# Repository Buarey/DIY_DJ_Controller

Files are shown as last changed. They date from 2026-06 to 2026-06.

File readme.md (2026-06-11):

# DIY DJ Controller



Homemade CDJ-style DJ controller with a 3D-printed enclosure, hand-built electronics, and custom firmware.

This repository documents:
- the current stable Mixxx prototype
- the firmware and Mixxx mapping that make it work
- the next hardware direction for a cleaner v2 build
- open-source hardware, firmware, and documentation for builders who want to contribute

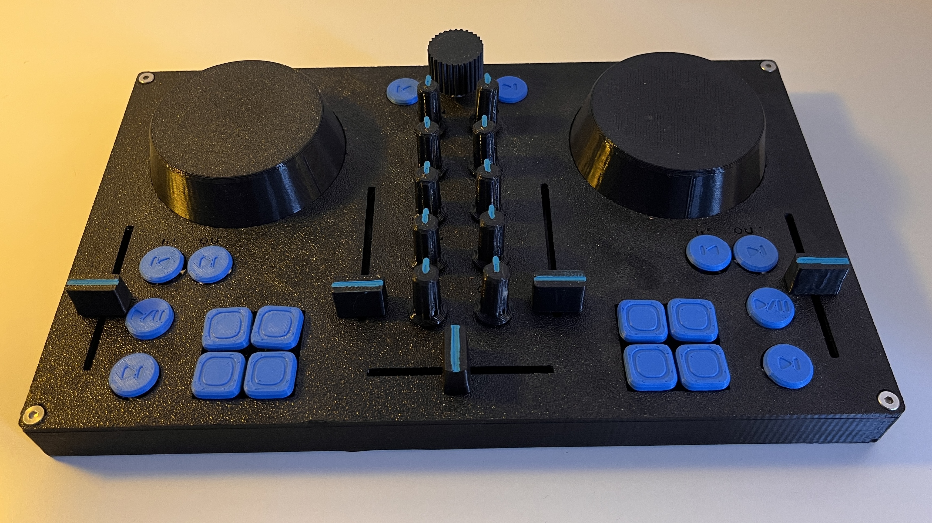
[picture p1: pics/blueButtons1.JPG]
DIY DJ controller with blue buttons


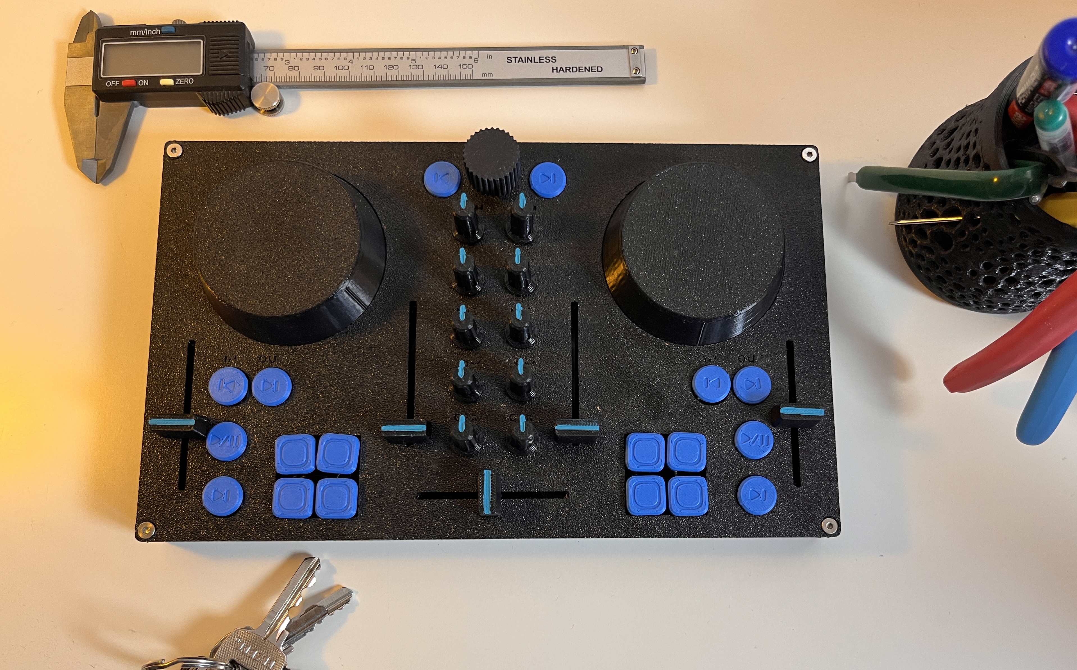
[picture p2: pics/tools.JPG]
DIY DJ controller with tools


<table>
  <tr>
    <td>Prototype top view before final buttons</td>
    <td>Hand-wired controller electronics</td>
  </tr>
  <tr>
    <td>Fusion 360 top assembly render</td>
    <td>Fusion 360 internal assembly render</td>
  </tr>
</table>

## Status

- `v1` is the stable Mixxx-focused version
- the controller has been built, flashed, and used successfully as a working prototype
- Rekordbox was tested, but the jog wheels never became usable enough for a real workflow
- because of that, Rekordbox is not a supported target for this hardware revision

## Current Version

- `MCU`: SparkFun Pro Micro / ATmega32U4
- `Firmware`: PlatformIO + Arduino + `MIDIUSB`
- `Inputs`: `PCF8575` for buttons, `74HC4067` for analog controls, 3 rotary encoders
- `Mechanical`: custom 3D-printed enclosure designed in Fusion 360
- `Software target`: Mixxx

The current prototype includes:
- two-deck transport and loop control
- EQ, filter, gain, volume, tempo, and crossfader control
- jog wheels
- music browsing and load controls

## V1 Hardware Summary

- `MCU`: SparkFun Pro Micro / ATmega32U4
- `Button expander`: `PCF8575` for 16 buttons
- `Analog mux`: `74HC4067` for 15 potentiometers
- `Encoders`: 3 total
  - 1 browse encoder
  - 2 jog wheel encoders
- `Encoder model`: Alps `EC11E` vertical rotary encoder, `H20mm`
- `Button model`: Omron `B3F-40xx`, 12x12 mm THT tactile switch
- `Direct buttons on MCU`: `A1`, `A2`, `A3`
- `Potentiometers`: 15 total
  - `Linear model`: `B103` 75 mm linear slide potentiometer, 10 kOhm
  - `Rotary model`: TT Electronics `P0915N` vertical rotary potentiometer

## V1 Materials List

This is the practical parts list for rebuilding the current working v1 prototype.

| Qty | Material | Notes |
| --- | --- | --- |
| 1 | SparkFun Pro Micro / ATmega32U4 board | The KiCad v1 schematic uses a USB-C Pro Micro clone footprint. Use the matching USB cable for the board you build with. |
| 1 | `PCF8575` / HW-331 16-bit I2C IO expander module | Handles the 16 deck buttons. |
| 1 | `CD74HC4067` / `74HC4067` 16-channel analog multiplexer module | Handles the 15 analog controls. |
| 18 | Omron `B3F-40xx` 12x12 mm THT tactile switches | 16 deck buttons plus 2 direct music-selection buttons. |
| 3 | Alps `EC11E` vertical rotary encoders, `H20mm` | 1 browse encoder plus 2 jog wheel encoders. |
| 10 | TT Electronics `P0915N` vertical rotary potentiometers | Gain, EQ, filter, and other rotary controls. |
| 5 | `B103` 75 mm linear slide potentiometers, 10 kOhm | Deck volume, tempo, and crossfader controls. |
| 1 | 3D-printed enclosure body | `3D models/DIY_CDJ_body.stl`. |
| 1 | 3D-printed enclosure lid | `3D models/DIY_CDJ_lid.stl`. |
| 1 each | 3D-printed caps and control parts | `crossfader.stl`, `cue.stl`, `encoder.stl`, `joggingWheel.stl`, `knob.stl`, `performance-pad.stl`, and `play-pause.stl`. |
| As needed | Hookup wire, solder, and 2.54 mm headers | The stable v1 prototype is hand-wired, not PCB-based. |

The firmware currently defines 3 direct music-selection inputs on `A1`, `A2`, and `A3`, but the KiCad v1 schematic places 18 tactile switches total. Add one extra switch if you wire all 3 direct inputs. The schematic also contains 16 resistor placeholders with no values or footprints assigned yet, so treat those as schematic TODOs rather than an order-ready BOM line.

## V1 Wiring Summary

These are the important firmware-defined connections for the current working Mixxx version.

### Wiring Diagrams

<p>
  Arduino wiring
  VCC wiring
  GND wiring
  Pull-up wiring
  Sensor signal wiring
</p>

### I2C / Button Expander

- `SDA` -> pin `2`
- `SCL` -> pin `3`
- `PCF8575` address is auto-detected on boot in the `0x20` to `0x27` range

### 74HC4067 Multiplexer

- `MUX signal` -> `A0`
- `S0` -> pin `15`
- `S1` -> pin `14`
- `S2` -> pin `16`
- `S3` -> pin `10`

### Rotary Encoders

- `Browse encoder` -> pins `4` and `5`
- `Jog wheel 1` -> pins `8` and `9`
- `Jog wheel 2` -> pins `6` and `7`

### Direct Buttons

- `A3` -> note `76`
- `A2` -> note `77`
- `A1` -> note `78`

## V1 Current Input Map

### PCF8575 Buttons

- `Button 0` -> Deck 1 Loop Out
- `Button 1` -> Deck 1 Loop In
- `Button 2` -> Deck 1 Hotcue 3
- `Button 3` -> Deck 1 Hotcue 4
- `Button 4` -> Deck 1 Hotcue 1
- `Button 5` -> Deck 1 Hotcue 2
- `Button 6` -> Deck 1 Cue
- `Button 7` -> Deck 1 Play/Pause
- `Button 8` -> Deck 2 Hotcue 4
- `Button 9` -> Deck 2 Hotcue 3
- `Button 10` -> Deck 2 Hotcue 1
- `Button 11` -> Deck 2 Hotcue 2
- `Button 12` -> Deck 2 Cue
- `Button 13` -> Deck 2 Play/Pause
- `Button 14` -> Deck 2 Loop In
- `Button 15` -> Deck 2 Loop Out

### Potentiometers

- `Pot 0 / CC 10` -> Deck 1 Gain
- `Pot 1 / CC 11` -> Deck 2 Gain
- `Pot 2 / CC 12` -> Deck 1 High EQ
- `Pot 3 / CC 13` -> Deck 2 High EQ
- `Pot 4 / CC 14` -> Deck 1 Mid EQ
- `Pot 5 / CC 15` -> Deck 2 Mid EQ
- `Pot 6 / CC 16` -> Deck 1 Low EQ
- `Pot 7 / CC 17` -> Deck 2 Low EQ
- `Pot 8 / CC 18` -> Deck 1 Filter
- `Pot 9 / CC 19` -> Deck 2 Filter
- `Pot 10 / CC 20` -> Deck 2 Volume
- `Pot 11 / CC 21` -> Deck 2 Tempo
- `Pot 12 / CC 22` -> Deck 1 Volume
- `Pot 13 / CC 23` -> Crossfader
- `Pot 14 / CC 24` -> Deck 1 Tempo

### Browser And Jog Controls

- `Browse encoder / CC 25` -> library scroll
- `A1 / note 78` -> Load selected track to Deck 1
- `A2 / note 77` -> Load selected track to Deck 2
- `A3 / note 76` -> Enter or expand selected folder
- `Jog wheel on pins 8/9 / CC 26` -> currently mapped to Deck 2
- `Jog wheel on pins 6/7 / CC 27` -> currently mapped to Deck 1

## V1 Firmware

The current firmware lives in `CDJ_firmware/src/main.cpp`.

### Current Behavior

- auto-detects the `PCF8575` on boot
- configures the expander pins as input pull-high
- reads 16 buttons through the `PCF8575`
- reads 15 analog controls through the `74HC4067`
- reads 3 rotary encoders
- reads direct top buttons on `A1`, `A2`, and `A3`
- sends MIDI note and CC messages through `MIDIUSB`
- uses an additional filter on the browse encoder to reduce event spam in Mixxx

### Build Target

`CDJ_firmware/platformio.ini` currently targets:

```ini
[env:sparkfun_promicro16]
platform = atmelavr
board = sparkfun_promicro16
framework = arduino
lib_deps =
  arduino-libraries/MIDIUSB @ ^1.0.5
```

## Repo Layout

- `CDJ_firmware/` - firmware source and PlatformIO config
- `controllers/mixx_Mapping/` - Mixxx XML and JS mapping
- `controllers/rekordbox/` - Rekordbox mapping reference and notes
- `pics/` - renders and prototype photos
- `reference circuits/` - circuit reference images
- `PCB/` - KiCad schematic, PCB, and custom symbols/footprints
- `3D models/` - printable parts and Fusion 360 source archive
- `CONTRIBUTING.md` - contribution guide
- `.github/` - issue templates, pull request template, and CI workflow

## Source Of Truth

- `Firmware`: `CDJ_firmware/src/main.cpp`
- `Mixxx XML mapping`: `controllers/mixx_Mapping/DJC-DIY.midi.xml`
- `Mixxx JS mapping`: `controllers/mixx_Mapping/DJC-DIY-scripts.js`

For exact control behavior, use those files instead of this README.

## Contributing

Contributions are welcome. The most useful contributions right now are practical build reports, Mixxx mapping fixes, firmware cleanup, PCB review, parts substitutions, enclosure fit notes, and documentation improvements.

Before starting a large hardware or firmware change, open an issue so the direction can be discussed. Small documentation fixes can go straight to a pull request.

Useful starter work:

- test the current Mixxx mapping on another OS or Mixxx version
- document compatible Pro Micro clones, encoders, buttons, and potentiometers
- improve wiring photos or assembly notes
- review the KiCad v1 schematic and PCB TODOs
- add real build notes for 3D-print settings and fit adjustments

See `CONTRIBUTING.md` for the full workflow and pull request checklist.

## Getting Started

### Firmware

1. Install [PlatformIO](https://platformio.org/) in VS Code.
2. Open `CDJ_firmware/`.
3. Connect the SparkFun Pro Micro by USB.
4. Build or upload:

```bash
pio run
pio run --target upload
```

### Mixxx

Copy these files into your Mixxx controller mapping folder:

- `controllers/mixx_Mapping/DJC-DIY.midi.xml`
- `controllers/mixx_Mapping/DJC-DIY-scripts.js`

Then enable the mapping in Mixxx.

## Important Notes

- The stable path for this project is Mixxx, not Rekordbox.
- The prototype is still hand-wired and not PCB-based yet.
- The current jog wheel assignment is swapped between physical control and deck mapping.
- Rekordbox support should be treated as future hardware research, not a feature of this version.

## V2 Plan

V2 is a hardware redesign focused on one goal: keep a single `USB-C` cable to the computer and add a built-in `3.5 mm` headphone cue output.

- `Master` stays on the computer side
- the controller provides only `Headphones / Cue`
- the project stays Mixxx-first

### Electronics Plan

- `Prototype MCU`: `SparkFun Thing Plus ESP32-S3`
- `Custom PCB MCU`: `ESP32-S3-WROOM-1`
- `Headphone audio`: `Adafruit TLV320DAC3100` or equivalent small I2S headphone DAC/codec
- `External ports`: one `USB-C`, one `3.5 mm TRS` headphone jack
- `Existing controls to keep initially`: `PCF8575`, `74HC4067`, jog encoders, browse encoder, buttons, and potentiometers

### Core Connections

- `USB-C` -> `ESP32-S3`
- `ESP32-S3 I2S` -> `TLV320DAC3100` audio data
- `ESP32-S3 I2C` -> `TLV320DAC3100` configuration
- `TLV320DAC3100` -> `3.5 mm TRS` headphone jack
- `ESP32-S3` -> existing control hardware

### Firmware Work

- port the controller logic from `ATmega32U4` to `ESP32-S3`
- expose one composite USB device with `MIDI + audio`
- keep the current control behavior as close to `v1` as possible
- send Mixxx cue audio to the headphone DAC

### Rekordbox Note

`ESP32-S3` is a much better platform for future USB experiments, but it does not guarantee Rekordbox compatibility or working jog wheels. V2 should still be treated as a Mixxx-first design.

## License

This project uses separate licenses by file type:

| Files | License |
| --- | --- |
| Firmware and controller mappings | GNU General Public License v3.0 only (`GPL-3.0-only`) |
| PCB, wiring, CAD, and 3D hardware design files | CERN Open Hardware Licence Version 2 - Strongly Reciprocal (`CERN-OHL-S-2.0`) |
| Documentation, photos, videos, and other media | Creative Commons Attribution 4.0 International (`CC-BY-4.0`) |

See `LICENSE.md`, `LICENSE-SOFTWARE.txt`, `LICENSE-HARDWARE.txt`, and `LICENSE-DOCS.txt` for details.

This project was inspired by my friend [@mandiclab](https://github.com/mandiclab) and the [djc-diy](https://github.com/mandiclab/djc-diy) project.

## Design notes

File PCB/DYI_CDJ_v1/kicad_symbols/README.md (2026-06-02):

# CDJ v1 KiCad Module Library

This project-local library contains schematic symbols and through-hole module footprints for the breakout boards shown in the project notes:

- `PCF8575_Module_HW331`
- `CD74HC4067_Module_Generic`
- `Arduino_Pro_Micro_USB_C`

KiCad should load them through the project-local `sym-lib-table` and `fp-lib-table` files.

The Arduino Pro Micro USB-C library was imported from:

https://github.com/jueta/Arduino_Pro_Micro_USB_C-Kicad-Library

The two module footprints were rebuilt from the linked product photos and corroborating supplier dimensions. They are drawn as component-side views: when the module is face-up, the silkscreen labels match the real board labels. Before ordering a PCB, print the footprints at 1:1 scale and place the physical boards over them.

Measurement references:

- Linked PCF8575 product photos and `21 mm x 32 mm` dimension image: https://www.aliexpress.com/item/1005009340294771.html
- Equivalent Open-Smart PCF8575 module listed as `33 mm x 21 mm`: https://www.tinytronics.nl/en/communication-and-signals/io-converters/open-smart-pcf8575-io-expander-module-16-extra-io-pins
- Linked HW-178 CD74HC4067 product photos: https://www.aliexpress.com/item/1005006309366590.html
- HW-178 supplier dimensions listed as `17 mm x 40 mm`: https://besomi.com/jo_en/hw-178-cd74hc4067-besomi-mux-module.html
- Equivalent standard 74HC4067 module dimensions listed as `40 mm x 18 mm`: https://protosupplies.com/product/16-ch-analog-digital-mux-module/

- Header pitch is 2.54 mm.
- PCF8575 board outline is nominally `21 mm x 32 mm`.
- PCF8575 left row, top to bottom: `P10`, `P11`, `P12`, `P13`, `P14`, `P15`, `P16`, `P17`, `VDD`, `GND`.
- PCF8575 right row, top to bottom: `P07`, `P06`, `P05`, `P04`, `P03`, `P02`, `P01`, `P00`, `VDD`, `GND`.
- PCF8575 bottom row, left to right: `GND`, `VCC`, `SDA`, `SCL`, `INT`.
- CD74HC4067 HW-178 board outline is nominally `40 mm x 18 mm`. Some suppliers report the width as `17 mm`; the header geometry is the same.
- CD74HC4067 left row, top to bottom: `C15` through `C0`.
- CD74HC4067 right row, top to bottom: `SIG`, `S3`, `S2`, `S1`, `S0`, `EN`, `VCC`, `GND`.
- Arduino Pro Micro USB-C board body is assumed to be `36.80 mm x 17.70 mm`.
- Arduino Pro Micro USB-C top row, USB-C on the left, left to right: `RAW`, `GND`, `RST`, `VCC`, `A3`, `A2`, `A1`, `A0`, `15`, `14`, `16`, `10`.
- Arduino Pro Micro USB-C bottom row, USB-C on the left, left to right: `TX0`, `RX1`, `GND`, `GND`, `2`, `3`, `4`, `5`, `6`, `7`, `8`, `9`.
- Board outlines match your exact modules. Daughterboard mounting holes are shown on `F.Fab` as reference marks only; they are intentionally not drilled into the carrier PCB.

The symbols use named pad numbers such as `SDA`, `P00`, and `C15`, so symbol pins and footprint pads map by signal name instead of fragile numeric pin order.

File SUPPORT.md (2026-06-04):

# Support

For build help, open an issue and include:

- Your operating system.
- Mixxx or Rekordbox version.
- Board model and USB connector type.
- Photos of the wiring or PCB area involved.
- The exact firmware commit or release you used.
- What you expected, what happened, and what you already tried.

For quick reports, use the issue templates. For larger design ideas, open a feature request before starting a big pull request.

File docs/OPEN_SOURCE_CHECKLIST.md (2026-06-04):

# Open Source Publishing Checklist

Use this checklist before making the GitHub repository public or announcing it.

## Repository

- Add the license files and `LICENSE.md` overview.
- Keep generated files out of commits: KiCad backups, `fp-info-cache`, `.kicad_prl`, PlatformIO build output, and `.DS_Store`.
- Confirm no personal files, credentials, private notes, or unfinished exports are tracked.
- Push the open-source preparation commit.

## GitHub Settings

- Set the repository visibility to public when ready.
- Enable Issues.
- Enable Discussions if you want build-help conversations separate from bug reports.
- Add topics: `diy-electronics`, `dj-controller`, `midi-controller`, `mixxx`, `platformio`, `arduino`, `kicad`, `open-hardware`, `3d-printing`.
- Add labels: `firmware`, `hardware`, `pcb`, `3d-models`, `mapping`, `docs`, `bug`, `enhancement`, `good first issue`, `help wanted`, `safety`.

## First Release

- Tag the current working Mixxx prototype as `v1.0.0`.
- Attach or link the firmware source, Mixxx mapping files, STL files, wiring images, and build notes.
- State that Rekordbox is experimental/unsupported for the current hardware revision.
- Mention known issues, especially swapped jog assignment and prototype hand-wiring.

## Community

- Create 3-5 starter issues that are genuinely approachable.
- Add one pinned issue for build reports.
- Ask contributors to include photos and version details when reporting hardware problems.

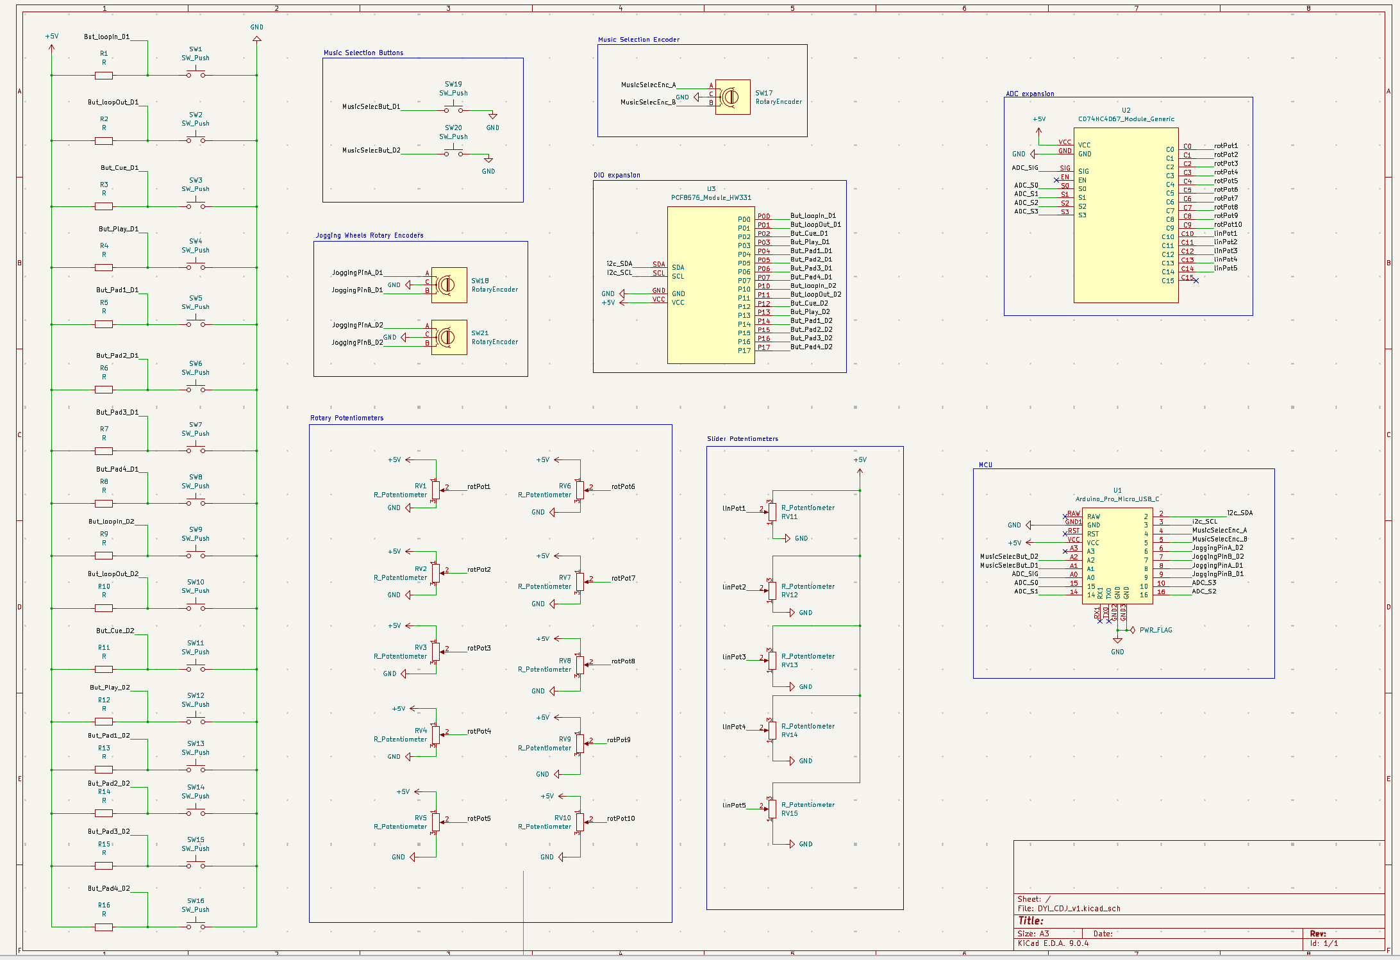
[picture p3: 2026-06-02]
pics/schematics_v1.png

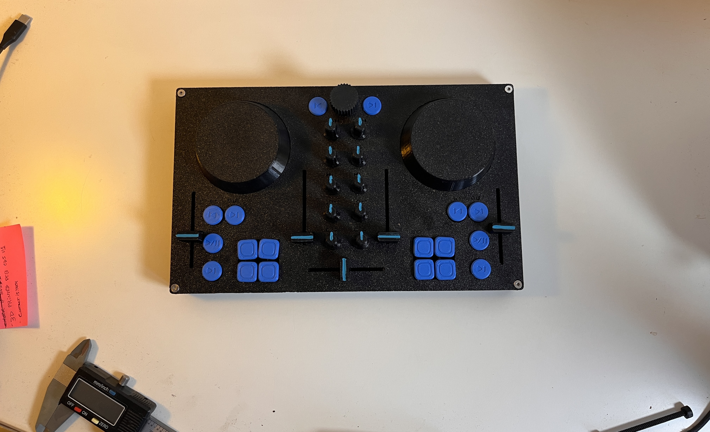
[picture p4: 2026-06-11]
pics/blueButtons3.JPG

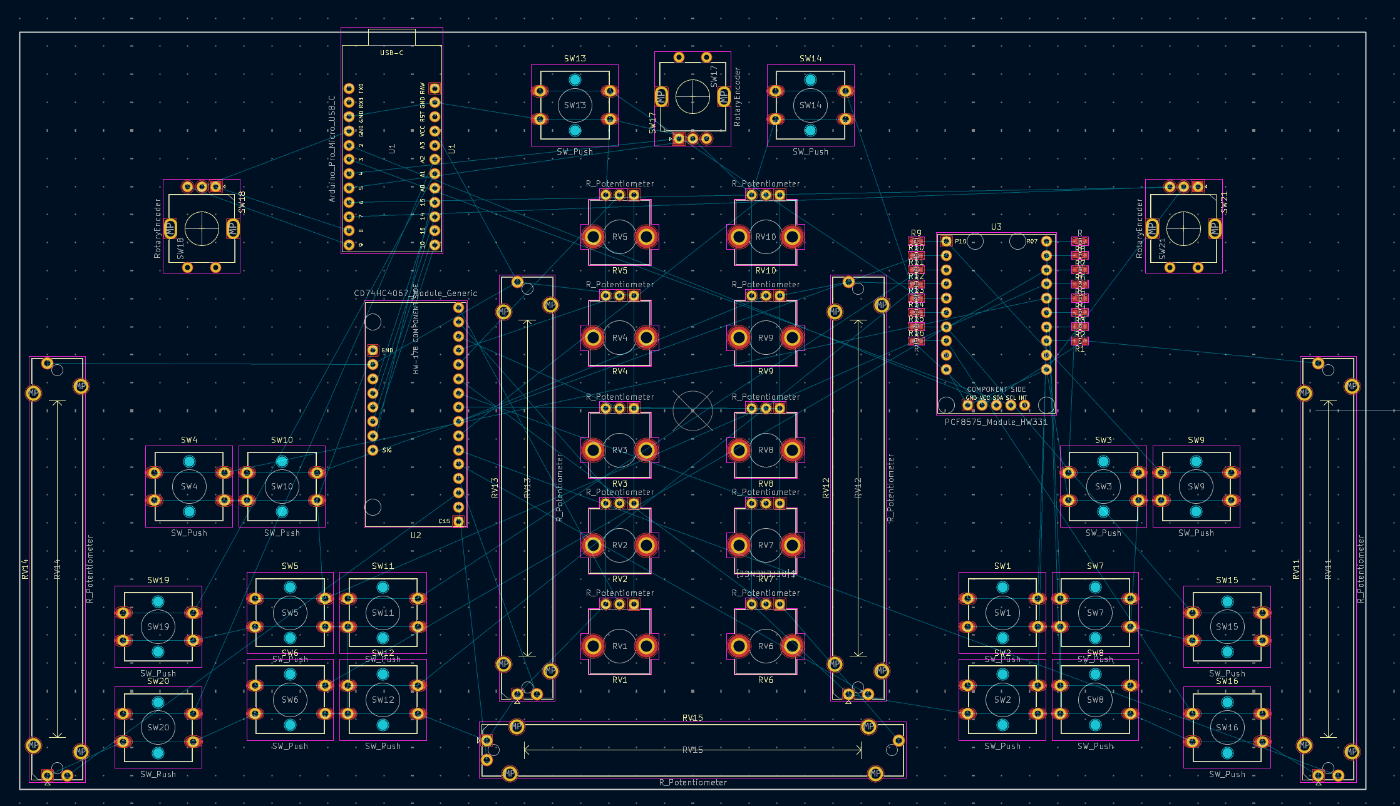
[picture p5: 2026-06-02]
pics/PCB_development_v1.png

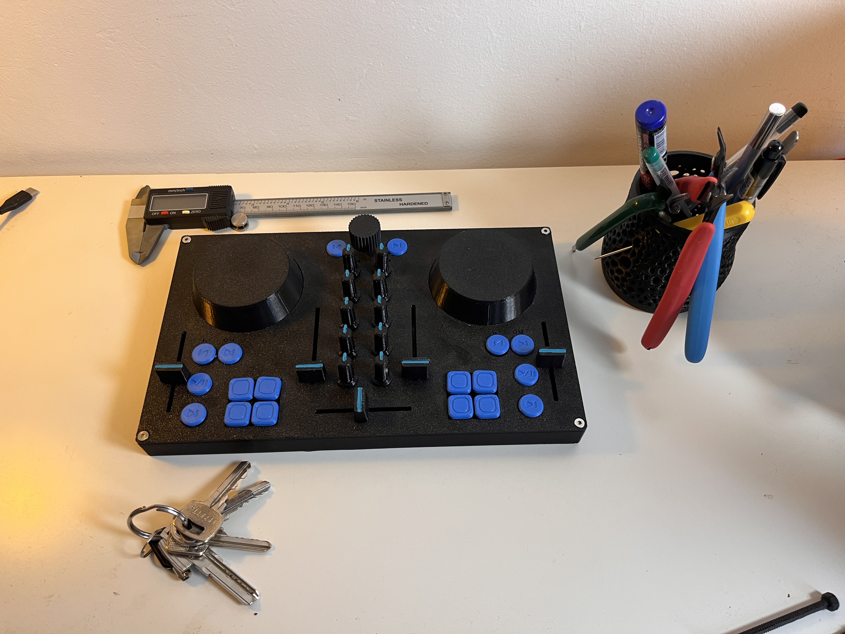
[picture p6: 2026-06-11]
pics/tools2.JPG

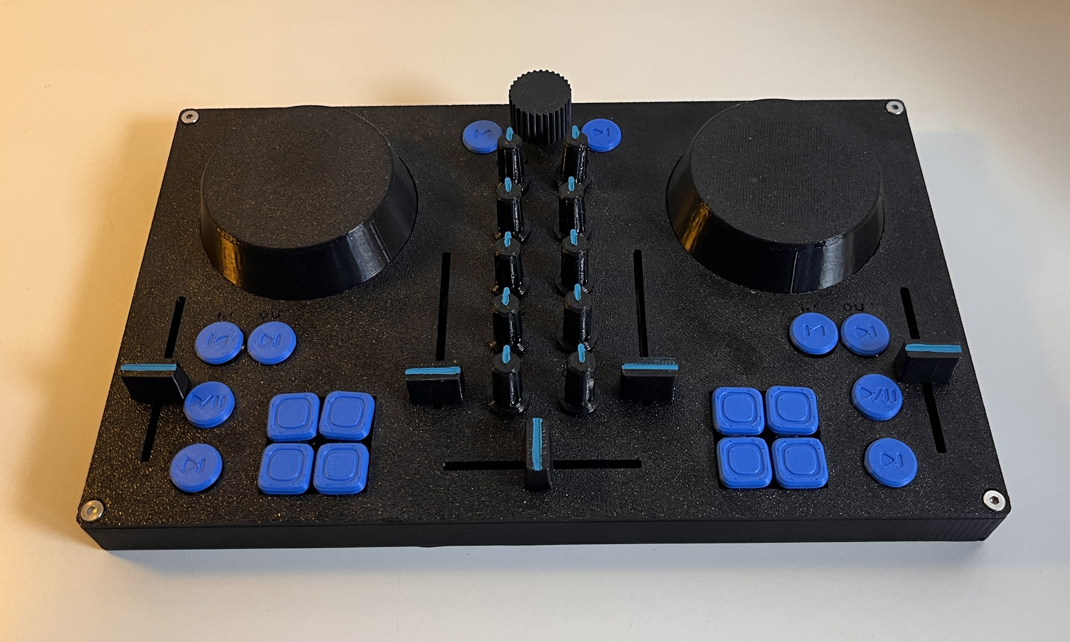
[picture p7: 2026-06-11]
pics/blueButtons4.JPG

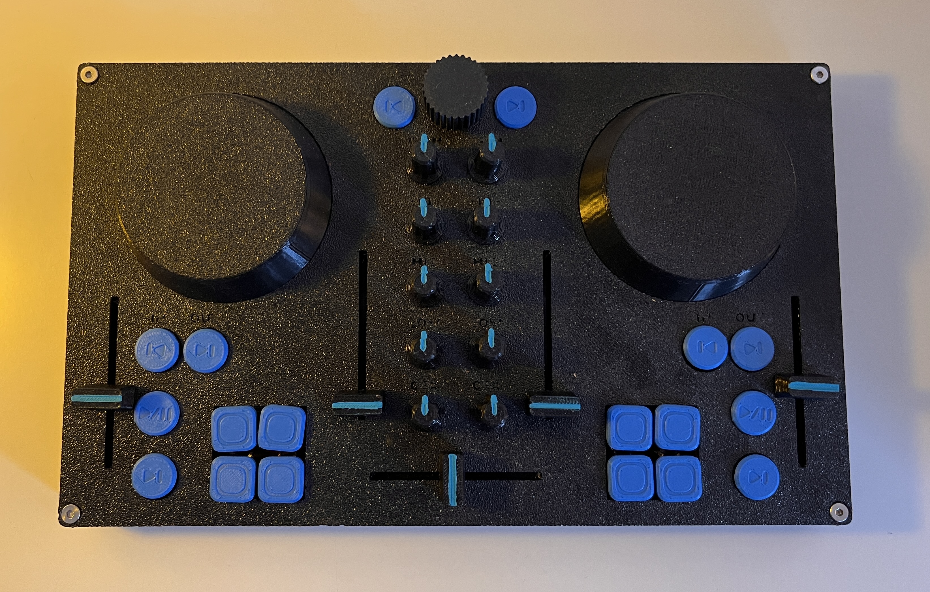
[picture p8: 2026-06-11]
pics/blueButtons2.JPG

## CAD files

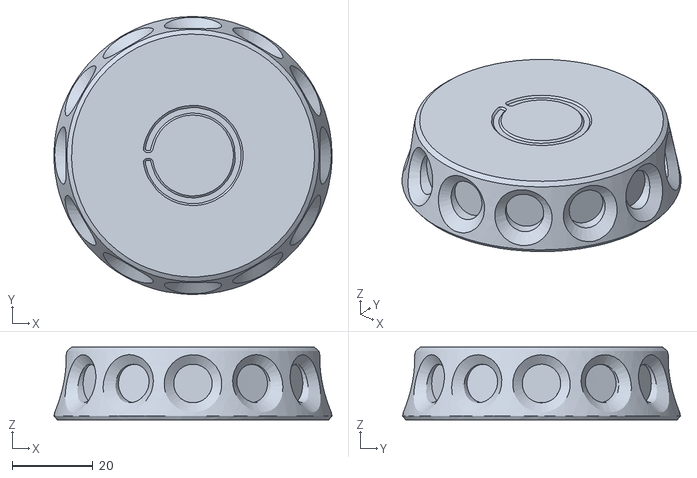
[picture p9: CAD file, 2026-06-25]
3D models/manda_jogwheel_big.stl
69.0 x 69.0 x 18.0

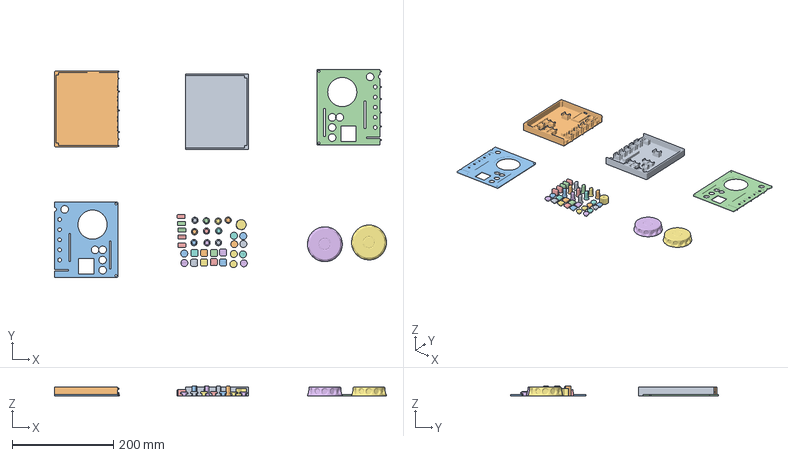
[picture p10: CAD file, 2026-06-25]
3D models/Orca_Slicer_Files/DIY_CDJ.3mf
656.0 x 411.9 x 20.0 mm
DIY_CDJ_body.stl x 2
DIY_CDJ_lid.stl_A
DIY_CDJ_lid.stl_B
crossfader.stl x 5
cue.stl x 2
encoder.stl
knob.stl x 10
performance-pad.stl x 8
play-pause.stl x 2
button_load_track.stl
button_round_clean.stl x 4
manda_jogwheel_big.stl x 2

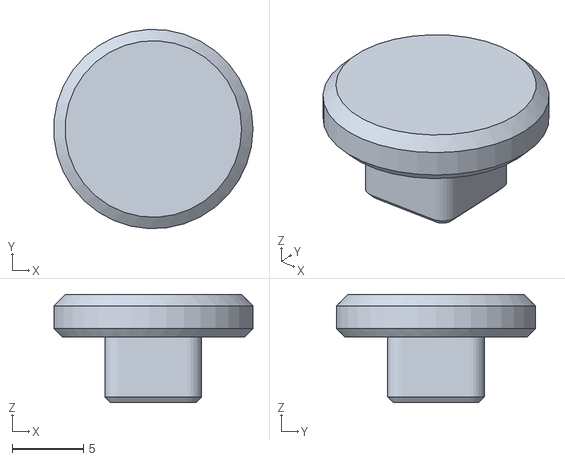
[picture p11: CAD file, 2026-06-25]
3D models/button_round_clean.stl
14.0 x 14.0 x 7.60

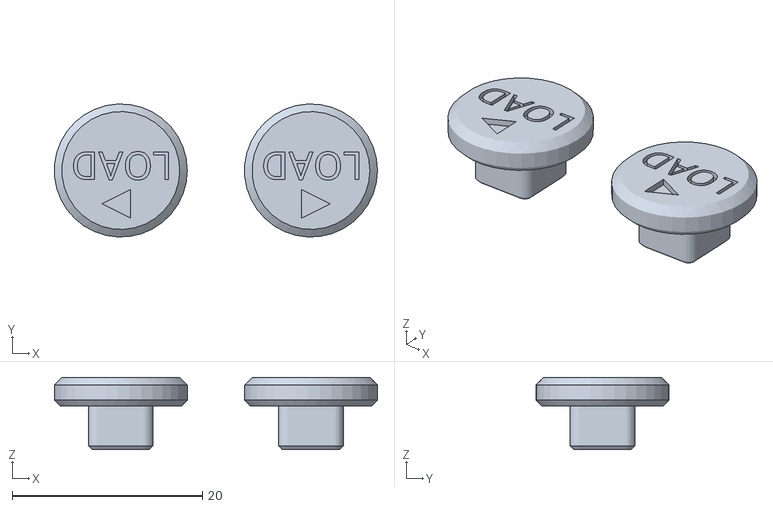
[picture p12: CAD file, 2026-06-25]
3D models/button_load_track.stl
34.0 x 14.0 x 7.60

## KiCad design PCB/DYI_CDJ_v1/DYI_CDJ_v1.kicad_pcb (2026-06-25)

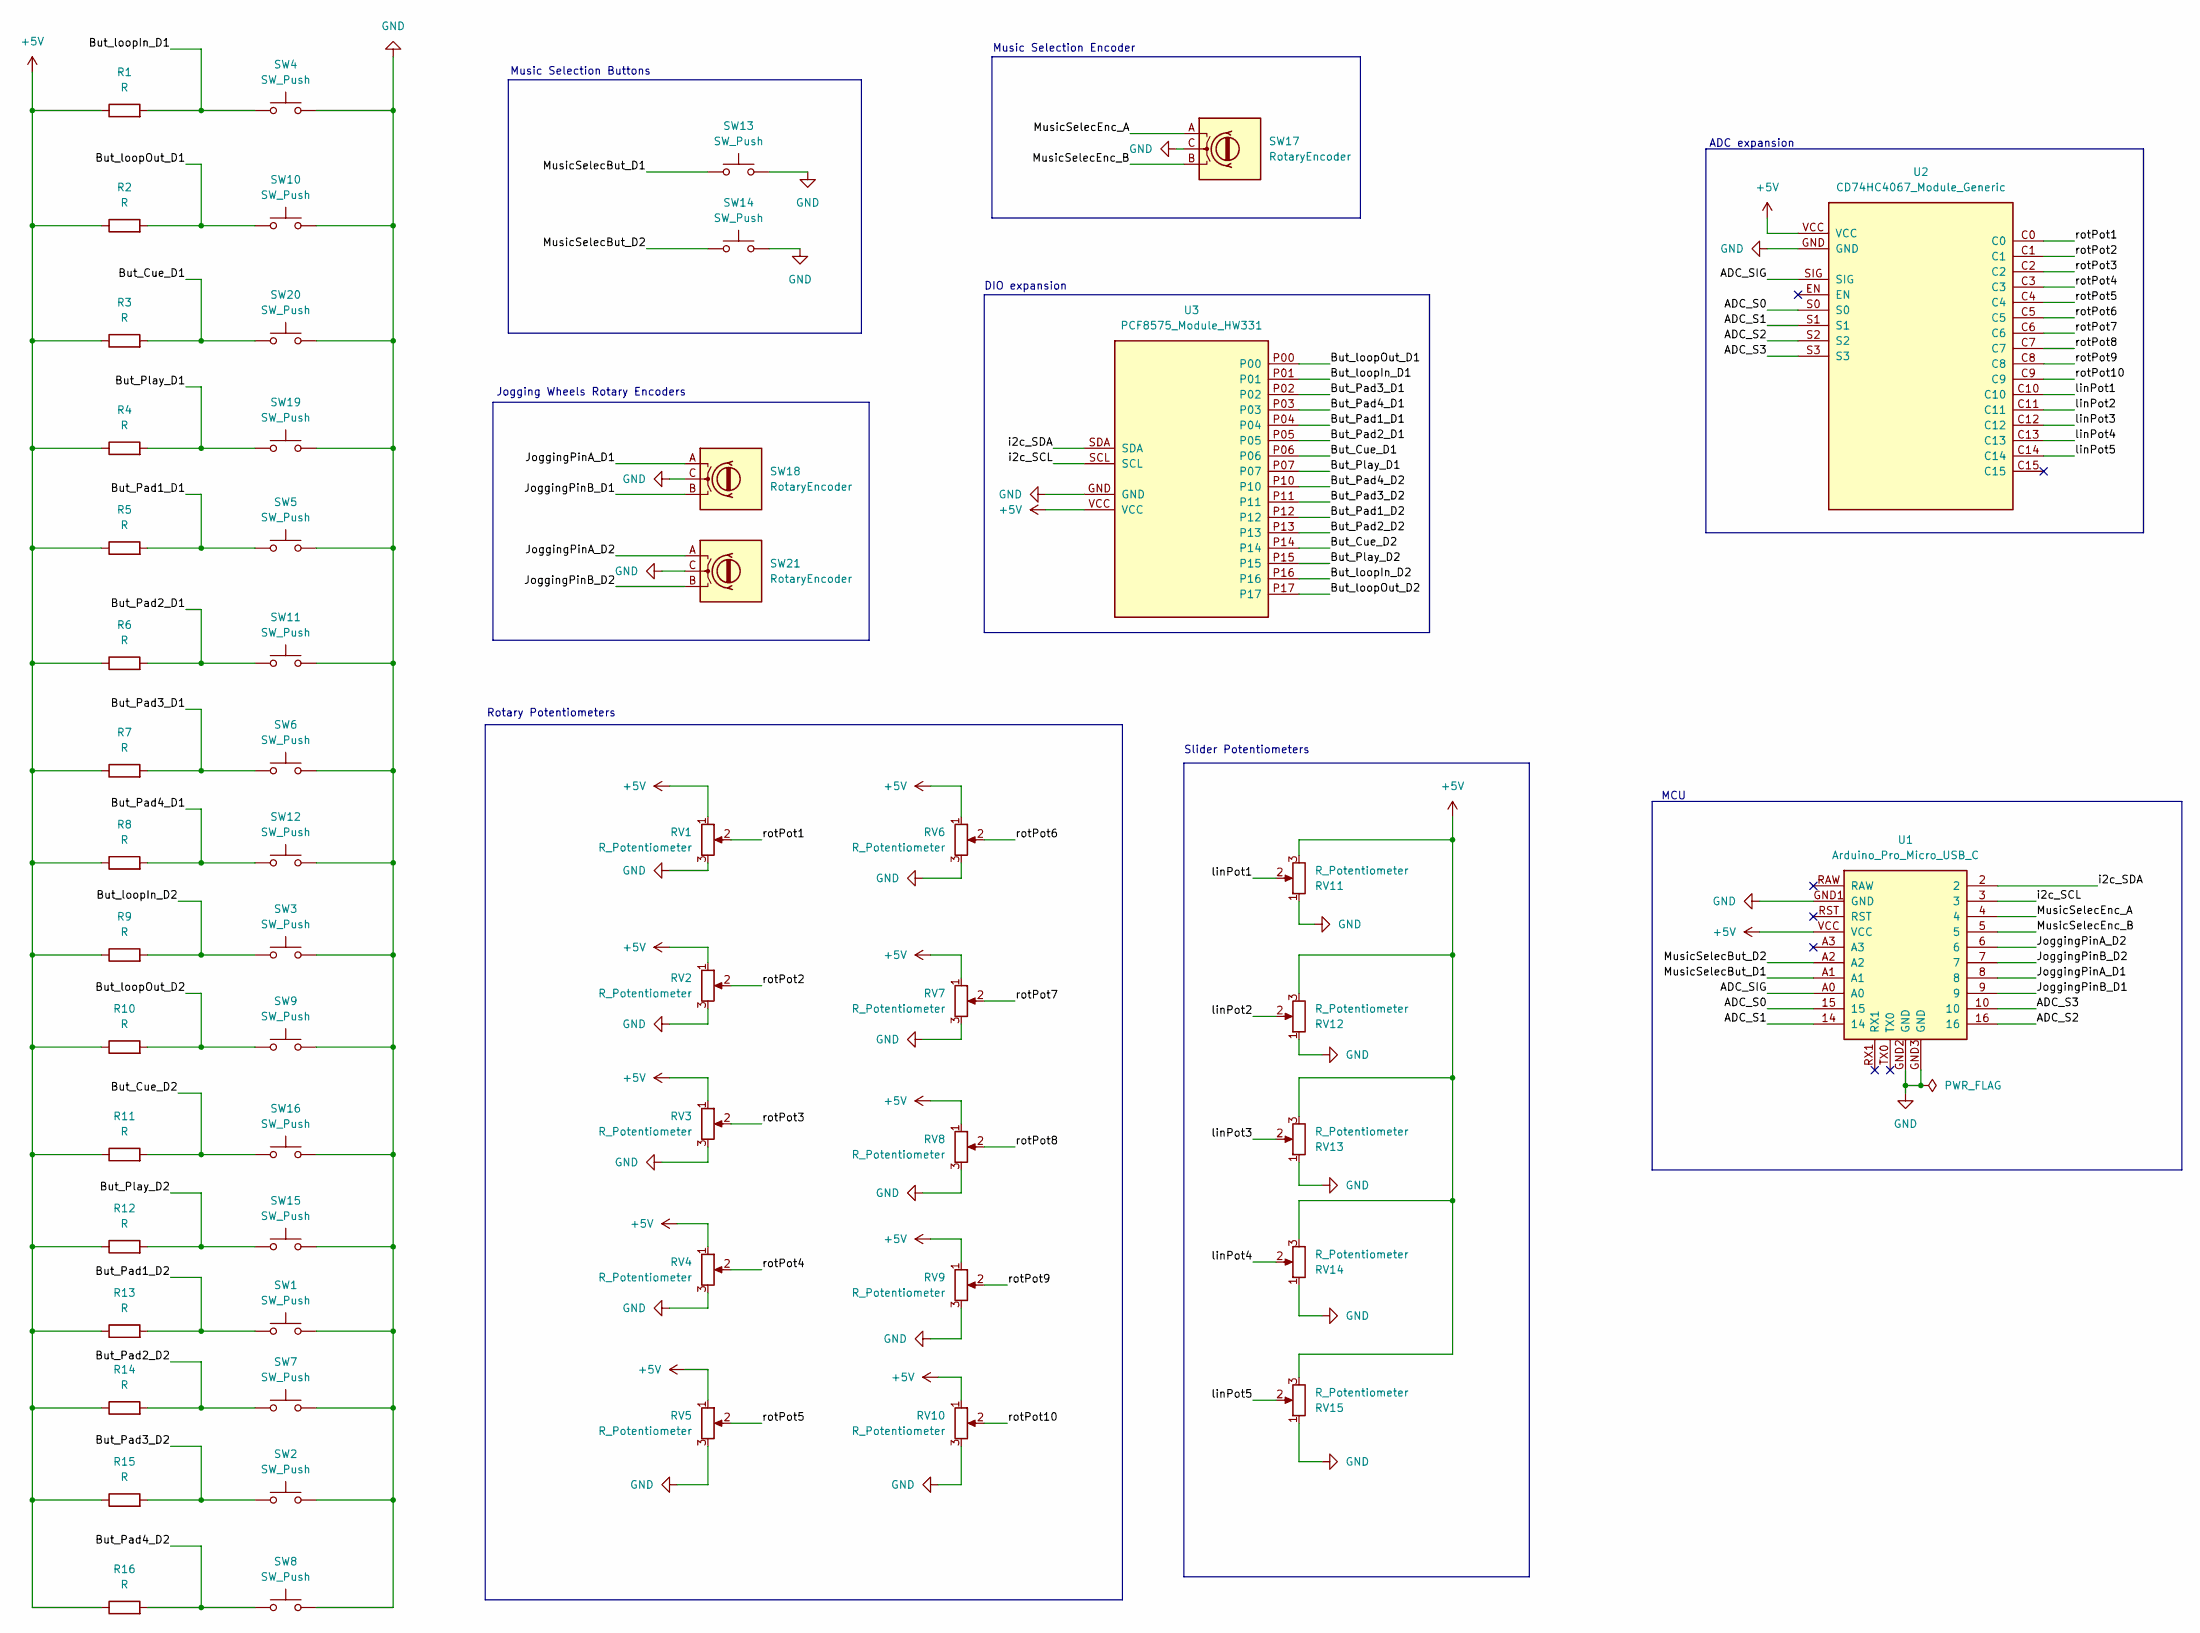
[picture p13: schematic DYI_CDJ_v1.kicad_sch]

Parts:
R1, R2, R3, R4, R5, R6, R7, R8, R9, R10, R11, R12, R13, R14, R15, R16: R; R_Axial_DIN0207_L6.3mm_D2.5mm_P10.16mm_Horizontal
RV1, RV2, RV3, RV4, RV5, RV6, RV7, RV8, RV9, RV10: R_Potentiometer; Potentiometer_TT_P0915N
RV11, RV12, RV13, RV14, RV15: R_Potentiometer; Potentiometer_Bourns_PTA6043_Single_Slide
SW1, SW2, SW3, SW4, SW5, SW6, SW7, SW8, SW9, SW10, SW11, SW12, SW13, SW14, SW15, SW16, SW19, SW20: SW_Push; SW_SPST_Omron_B3F-40xx
SW17, SW18, SW21: RotaryEncoder; RotaryEncoder_Alps_EC11E_Vertical_H20mm
U1: Arduino_Pro_Micro_USB_C; Arduino_Pro_Micro_USB_C_36.8x17.7mm
U2: CD74HC4067_Module_Generic
U3: PCF8575_Module_HW331

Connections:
+5V: R1.1, R2.1, R3.1, R4.1, R5.1, R6.1, R7.1, R8.1, R9.1, R10.1, R11.1, R12.1, R13.1, R14.1, R15.1, R16.1, RV1.1, RV2.1, RV3.1, RV4.1, RV5.1, RV6.1, RV7.1, RV8.1, RV9.1, RV10.1, RV11.3, RV12.3, RV13.3, RV14.3, RV15.3, U1.VCC, U2.VCC, U3.VCC
/ADC_S0: U1.15, U2.S0
/ADC_S1: U1.14, U2.S1
/ADC_S2: U1.16, U2.S2
/ADC_S3: U1.10, U2.S3
/ADC_SIG: U1.A0, U2.SIG
/But_Cue_D1: R3.2, SW20.1, U3.P06
/But_Cue_D2: R11.2, SW16.1, U3.P14
/But_Pad1_D1: R5.2, SW5.1, U3.P04
/But_Pad1_D2: R13.2, SW1.1, U3.P12
/But_Pad2_D1: R6.2, SW11.1, U3.P05
/But_Pad2_D2: R14.2, SW7.1, U3.P13
/But_Pad3_D1: R7.2, SW6.1, U3.P02
/But_Pad3_D2: R15.2, SW2.1, U3.P11
/But_Pad4_D1: R8.2, SW12.1, U3.P03
/But_Pad4_D2: R16.2, SW8.1, U3.P10
/But_Play_D1: R4.2, SW19.1, U3.P07
/But_Play_D2: R12.2, SW15.1, U3.P15
/But_loopIn_D1: R1.2, SW4.1, U3.P01
/But_loopIn_D2: R9.2, SW3.1, U3.P16
/But_loopOut_D1: R2.2, SW10.1, U3.P00
/But_loopOut_D2: R10.2, SW9.1, U3.P17
/JoggingPinA_D1: SW18.A, U1.8
/JoggingPinA_D2: SW21.A, U1.6
/JoggingPinB_D1: SW18.B, U1.9
/JoggingPinB_D2: SW21.B, U1.7
/MusicSelecBut_D1: SW13.1, U1.A1
/MusicSelecBut_D2: SW14.1, U1.A2
/MusicSelecEnc_A: SW17.A, U1.4
/MusicSelecEnc_B: SW17.B, U1.5
/i2c_SCL: U1.3, U3.SCL
/i2c_SDA: U1.2, U3.SDA
/linPot1: RV11.2, U2.C10
/linPot2: RV12.2, U2.C11
/linPot3: RV13.2, U2.C12
/linPot4: RV14.2, U2.C13
/linPot5: RV15.2, U2.C14
/rotPot1: RV1.2, U2.C0
/rotPot2: RV2.2, U2.C1
/rotPot3: RV3.2, U2.C2
/rotPot4: RV4.2, U2.C3
/rotPot5: RV5.2, U2.C4
/rotPot6: RV6.2, U2.C5
/rotPot7: RV7.2, U2.C6
/rotPot8: RV8.2, U2.C7
/rotPot9: RV9.2, U2.C8
/rotPot10: RV10.2, U2.C9
GND: RV1.3, RV2.3, RV3.3, RV4.3, RV5.3, RV6.3, RV7.3, RV8.3, RV9.3, RV10.3, RV11.1, RV12.1, RV13.1, RV14.1, RV15.1, SW1.2, SW2.2, SW3.2, SW4.2, SW5.2, SW6.2, SW7.2, SW8.2, SW9.2, SW10.2, SW11.2, SW12.2, SW13.2, SW14.2, SW15.2, SW16.2, SW17.C, SW18.C, SW19.2, SW20.2, SW21.C, U1.GND1 (GND), U1.GND2 (GND), U1.GND3 (GND), U2.GND, U3.GND

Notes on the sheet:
Music Selection Buttons
Music Selection Encoder
DIO expansion
Jogging Wheels Rotary Encoders
Slider Potentiometers
ADC expansion
Rotary Potentiometers
MCU

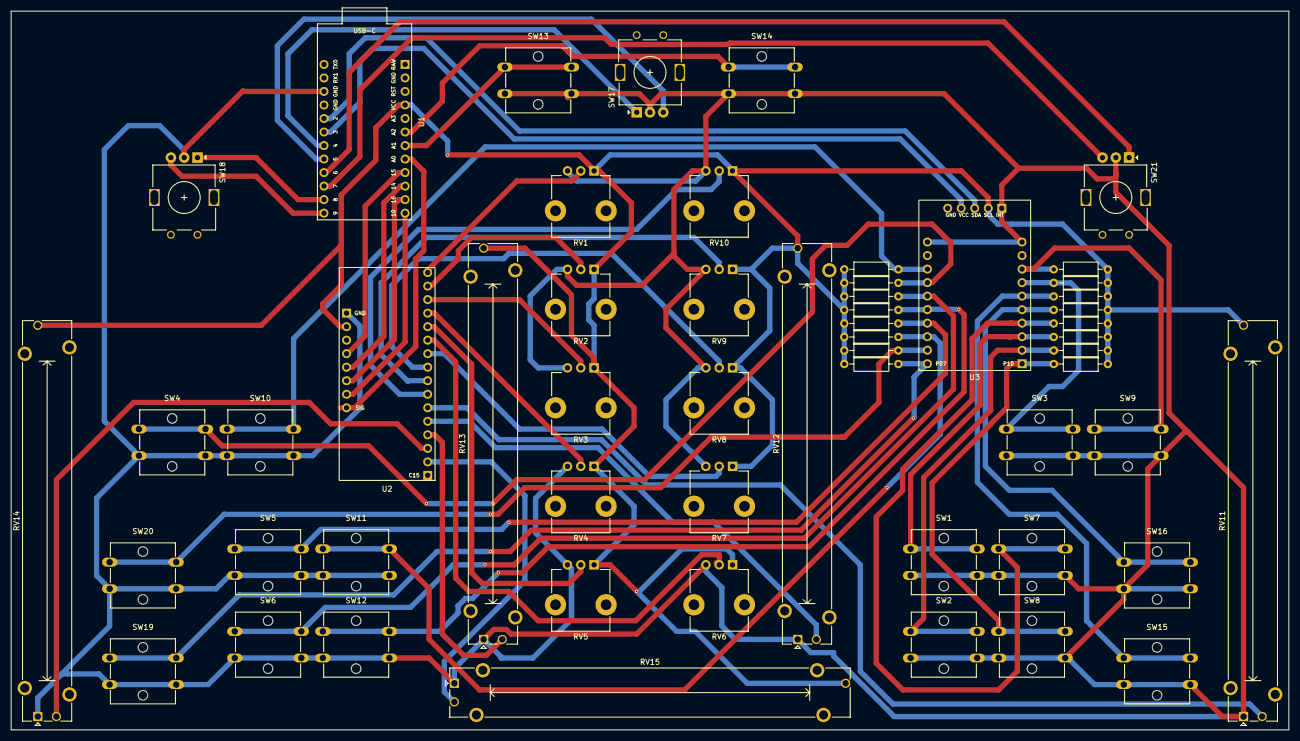
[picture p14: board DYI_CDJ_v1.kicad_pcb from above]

Board: 2 copper layers, 240.0 x 135.0 mm, 55 parts (0 on the bottom side), 48 nets.

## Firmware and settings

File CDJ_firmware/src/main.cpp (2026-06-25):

#include <Arduino.h>
#include <MIDIUSB.h>
#include <Wire.h>

// ---------- PCF8575 IO EXPANDER (16 PUSH BUTTONS) ----------
// PCF8575 address is detected on boot across the valid 0x20-0x27 range.
const byte PCF8575_ADDR_START = 0x20;
const byte PCF8575_ADDR_END = 0x27;
byte pcf8575Addr = 0;
const byte buttonNotes[] = {60, 61, 62, 63, 64, 65, 66, 67, 68, 69, 70, 71, 72, 73, 74, 75};
bool buttonStates[16] = {0};

// ---------- 74HC4067 MULTIPLEXER (15 POTENTIOMETERS) ----------
// Selection pins for the multiplexer
const int MUX_S0 = 15;
const int MUX_S1 = 14;
const int MUX_S2 = 16;
const int MUX_S3 = 10;
const int MUX_INPUT = A0; // Analog input from multiplexer

const byte potCCs[] = {10, 11, 12, 13, 14, 15, 16, 17, 18, 19, 20, 21, 22, 23, 24};
int potValues[15] = {0};
const int potThreshold = 2;

// ---------- ROTARY ENCODERS ----------
// Music selection encoder (top middle)
const int encoderA_Music = 4;
const int encoderB_Music = 5;
const byte encoderCC_Music = 25;
bool encoderLastState_Music = 0;

// Jog wheel encoder 1
const int encoderA_Jog1 = 8;
const int encoderB_Jog1 = 9;
const byte encoderCC_Jog1 = 26;
bool encoderLastState_Jog1 = 0;

// Jog wheel encoder 2
const int encoderA_Jog2 = 6;
const int encoderB_Jog2 = 7;
const byte encoderCC_Jog2 = 27;
bool encoderLastState_Jog2 = 0;

// ---------- PUSH BUTTONS ON ARDUINO PINS (with software pullup) ----------
// Music selection buttons (top)
const int buttonPin_A3 = A3;
const int buttonPin_A2 = A2;
const int buttonPin_A1 = A1;
const byte buttonNote_A3 = 76;
const byte buttonNote_A2 = 77;
const byte buttonNote_A1 = 78;
bool buttonState_A3 = false;
bool buttonState_A2 = false;
bool buttonState_A1 = false;

// ---------- FUNCTION DECLARATIONS ----------
void noteOn(byte pitch);
void noteOff(byte pitch);
void handlePots();
void selectMuxChannel(int channel);
void sendCC(byte cc, byte val);
void handleEncoders();
uint16_t readPCF8575();
bool detectPCF8575();
void configurePCF8575Inputs();

void setup()
{
   Serial.begin(115200);
   delay(1000);
  // Serial.println("Booting DJ controller...");

  // Initialize I2C for PCF8575
  Wire.begin();
  delay(500); // Give I2C time to initialize

  if (detectPCF8575())
  {
    configurePCF8575Inputs();
    // Serial.print("PCF8575 detected at 0x");
    // Serial.println(pcf8575Addr, HEX);
  }
  else
  {
    // Serial.println("No PCF8575 found on I2C addresses 0x20-0x27");
  }

  // Initialize multiplexer selection pins
  pinMode(MUX_S0, OUTPUT);
  pinMode(MUX_S1, OUTPUT);
  pinMode(MUX_S2, OUTPUT);
  pinMode(MUX_S3, OUTPUT);

  // Initialize music selection encoder pins
  pinMode(encoderA_Music, INPUT_PULLUP);
  pinMode(encoderB_Music, INPUT_PULLUP);
  encoderLastState_Music = digitalRead(encoderA_Music);

  // Initialize jog wheel encoder 1 pins
  pinMode(encoderA_Jog1, INPUT_PULLUP);
  pinMode(encoderB_Jog1, INPUT_PULLUP);
  encoderLastState_Jog1 = digitalRead(encoderA_Jog1);

  // Initialize jog wheel encoder 2 pins
  pinMode(encoderA_Jog2, INPUT_PULLUP);
  pinMode(encoderB_Jog2, INPUT_PULLUP);
  encoderLastState_Jog2 = digitalRead(encoderA_Jog2);

  // Initialize music selection button pins with software pullup
  pinMode(buttonPin_A3, INPUT_PULLUP);
  pinMode(buttonPin_A2, INPUT_PULLUP);
  pinMode(buttonPin_A1, INPUT_PULLUP);
}

void loop()
{
  // ------------------ PUSH BUTTONS (PCF8575) ------------------
  uint16_t buttonData = readPCF8575();

  for (int i = 0; i < 16; i++)
  {
    bool pressed = !(bitRead(buttonData, i)); // Active LOW

    if (pressed && !buttonStates[i])
    {
       Serial.print("Button ");
       Serial.print(i);
       Serial.print(" pressed - Note: ");
       Serial.println(buttonNotes[i]);

      noteOn(buttonNotes[i]);
      buttonStates[i] = true;
    }
    else if (!pressed && buttonStates[i])
    {
      // Serial.print("Button ");
      // Serial.print(i);
      // Serial.println(" released");

      noteOff(buttonNotes[i]);
      buttonStates[i] = false;
    }
  }

  // ------------------ MUSIC SELECTION BUTTONS (A3, A2, A1) ------------------
  // Button on A3
  bool pressedA3 = !digitalRead(buttonPin_A3);
  if (pressedA3 && !buttonState_A3)
  {
    // Serial.println("Button A3 pressed - Note: 76");
    noteOn(buttonNote_A3);
    buttonState_A3 = true;
  }
  else if (!pressedA3 && buttonState_A3)
  {
    // Serial.println("Button A3 released");
    noteOff(buttonNote_A3);
    buttonState_A3 = false;
  }

  // Button on A2
  bool pressedA2 = !digitalRead(buttonPin_A2);
  if (pressedA2 && !buttonState_A2)
  {
    // Serial.println("Button A2 pressed - Note: 77");
    noteOn(buttonNote_A2);
    buttonState_A2 = true;
  }
  else if (!pressedA2 && buttonState_A2)
  {
    // Serial.println("Button A2 released");
    noteOff(buttonNote_A2);
    buttonState_A2 = false;
  }

  // Button on A1
  bool pressedA1 = !digitalRead(buttonPin_A1);
  if (pressedA1 && !buttonState_A1)
  {
    // Serial.println("Button A1 pressed - Note: 78");
    noteOn(buttonNote_A1);
    buttonState_A1 = true;
  }
  else if (!pressedA1 && buttonState_A1)
  {
    // Serial.println("Button A1 released");
    noteOff(buttonNote_A1);
    buttonState_A1 = false;
  }

  handlePots();

  handleEncoders();

  delay(2); // Reduced debounce for faster response
}

// ------------------ MIDI FUNCTIONS ------------------

void noteOn(byte pitch)
{
  midiEventPacket_t noteOnMsg = {0x09, 0x90, pitch, 127};
  MidiUSB.sendMIDI(noteOnMsg);
  MidiUSB.flush();
}

void noteOff(byte pitch)
{
  midiEventPacket_t noteOffMsg = {0x08, 0x80, pitch, 0};
  MidiUSB.sendMIDI(noteOffMsg);
  MidiUSB.flush();
}

void handlePots()
{
  static unsigned long lastReadTime = 0;
  const unsigned long readInterval = 5; // Faster polling (was 10ms)

  if (millis() - lastReadTime < readInterval)
    return;
  lastReadTime = millis();

  for (int i = 0; i < 15; i++)
  {
    // Select the channel on the multiplexer
    selectMuxChannel(i);

    // Read the analog value
    int raw = analogRead(MUX_INPUT);
    int mapped = raw / 8;

    if (abs(mapped - potValues[i]) >= potThreshold)
    {
      // Serial.print("Pot ");
      // Serial.print(i);
      // Serial.print(" (CC ");
      // Serial.print(potCCs[i]);
      // Serial.print("): ");
      // Serial.println(mapped);

      potValues[i] = mapped;
      sendCC(potCCs[i], mapped);
    }
  }
}

// Select channel on 74HC4067 multiplexer
void selectMuxChannel(int channel)
{
  digitalWrite(MUX_S0, bitRead(channel, 0));
  digitalWrite(MUX_S1, bitRead(channel, 1));
  digitalWrite(MUX_S2, bitRead(channel, 2));
  digitalWrite(MUX_S3, bitRead(channel, 3));
  delayMicroseconds(5); // Reduced settling time for faster response
}

void sendCC(byte cc, byte val)
{
  midiEventPacket_t ccMsg = {0x0B, 0xB0, cc, val};
  MidiUSB.sendMIDI(ccMsg);
  MidiUSB.flush();
}

void handleEncoders()
{
  static unsigned long lastMusicEncoderEventTime = 0;
  const unsigned long musicEncoderIntervalMs = 8;

  // ---------- MUSIC SELECTION ENCODER (pins 4, 5) ----------
  int currentState_Music = digitalRead(encoderA_Music);
  if (currentState_Music != encoderLastState_Music)
  {
    unsigned long now = millis();
    int bState = digitalRead(encoderB_Music);
    encoderLastState_Music = currentState_Music;

    if (now - lastMusicEncoderEventTime >= musicEncoderIntervalMs)
    {
      // Only emit on one edge of phase A to avoid double-triggering per detent.
      if (currentState_Music == LOW)
      {
        byte directionValue;

        if (currentState_Music == bState)
        {
          directionValue = 0x41;
          // Serial.println("Music Encoder - CW");
        }
        else
        {
          directionValue = 0x3F;
          // Serial.println("Music Encoder - CCW");
        }

        midiEventPacket_t cc = {0x0B, 0xB0, encoderCC_Music, directionValue};
        MidiUSB.sendMIDI(cc);
        MidiUSB.flush();
        lastMusicEncoderEventTime = now;
      }
    }
  }

  // ---------- JOG WHEEL ENCODER 1 (pins 8, 9) ----------
  int currentState_Jog1 = digitalRead(encoderA_Jog1);
  if (currentState_Jog1 != encoderLastState_Jog1)
  {
    int bState = digitalRead(encoderB_Jog1);
    byte directionValue;

    if (currentState_Jog1 == bState)
    {
      directionValue = 0x41;
      // Serial.println("Jog Wheel 1 - CW");
    }
    else
    {
      directionValue = 0x3F;
      // Serial.println("Jog Wheel 1 - CCW");
    }

    midiEventPacket_t cc = {0x0B, 0xB0, encoderCC_Jog1, directionValue};
    MidiUSB.sendMIDI(cc);
    MidiUSB.flush();

    encoderLastState_Jog1 = currentState_Jog1;
  }

  // ---------- JOG WHEEL ENCODER 2 (pins 6, 7) ----------
  int currentState_Jog2 = digitalRead(encoderA_Jog2);
  if (currentState_Jog2 != encoderLastState_Jog2)
  {
    int bState = digitalRead(encoderB_Jog2);
    byte directionValue;

    if (currentState_Jog2 == bState)
    {
      directionValue = 0x41;
      // Serial.println("Jog Wheel 2 - CW");
    }
    else
    {
      directionValue = 0x3F;
      // Serial.println("Jog Wheel 2 - CCW");
    }

    midiEventPacket_t cc = {0x0B, 0xB0, encoderCC_Jog2, directionValue};
    MidiUSB.sendMIDI(cc);
    MidiUSB.flush();

    encoderLastState_Jog2 = currentState_Jog2;
  }
}

// ---------- PCF8575 I2C FUNCTIONS ----------

// Read all 16 inputs from PCF8575 as a 16-bit value
uint16_t readPCF8575()
{
  static unsigned long lastWarning = 0;

  if (pcf8575Addr == 0)
  {
    if (millis() - lastWarning > 1000)
    {
      // Serial.println("Skipping PCF8575 read: no expander detected");
      lastWarning = millis();
    }
    return 0xFFFF;
  }

  Wire.requestFrom(pcf8575Addr, (uint8_t)2); // Request 2 bytes

  uint8_t low = 0xFF; // Default to all 1s (unpressed)
  uint8_t high = 0xFF;

  if (Wire.available() >= 1)
  {
    low = Wire.read();
  }
  if (Wire.available() >= 1)
  {
    high = Wire.read();
  }

  // Combine into 16-bit value
  uint16_t value = ((uint16_t)high << 8) | low;
  return value;
}

bool detectPCF8575()
{
  for (byte addr = PCF8575_ADDR_START; addr <= PCF8575_ADDR_END; addr++)
  {
    Wire.beginTransmission(addr);
    byte error = Wire.endTransmission();
    if (error == 0)
    {
      pcf8575Addr = addr;
      return true;
    }
  }

  pcf8575Addr = 0;
  return false;
}

void configurePCF8575Inputs()
{
  // PCF8575 uses quasi-bidirectional pins. Writing HIGH configures pins as inputs.
  Wire.beginTransmission(pcf8575Addr);
  Wire.write(0xFF);
  Wire.write(0xFF);
  byte error = Wire.endTransmission();

  if (error == 0)
  {
     Serial.println("PCF8575 configured for input pull-high");
  }
  else
  {
     Serial.print("PCF8575 init write failed, error=");
     Serial.println(error);
  }
}

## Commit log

2026-05-10 Add v1 materials list to README
2026-05-10 Correct v1 button materials count
2026-06-02 developing PCB
    [DYI_CDJ_v1.kicad_pcb, DYI_CDJ_v1.kicad_sch]
2026-06-25 PCB update dev
    [DYI_CDJ_v1.kicad_pcb, DYI_CDJ_v1.kicad_sch]
2026-06-25 Models and modifed source code
    Added missig 3D models + alternatives
    Added alternative Mixxx mapping
    Replaced original source code with modified one (tact buttons didn't work after reboot)
    [DIY_CDJ.3mf, button_load_track.stl, button_round_clean.stl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]
